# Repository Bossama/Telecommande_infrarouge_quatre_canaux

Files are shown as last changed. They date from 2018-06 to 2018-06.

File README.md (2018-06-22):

# Telecommande_infrarouge_quatre_canaux

Notre Mini Projet intituler télécommande a 4 cannas composer de deux cartes électroniques :

Le 1er est un émetteur possède 4 bouton dont chaque à leur propre période 

Le 2 -ème est un récepteur qui va traiter le signal délivrer par l’émetteur et puis (après une phase de sélection) ce signal va 
assurer soit la mise en marche ou l’arrêt de l’une des 4 canaux dont deux voix en 12V DC et deux autres en 220V AC. 

Programme utiliser : Eagle 7.7 win64
                     https://www.autodesk.com/products/eagle/overview

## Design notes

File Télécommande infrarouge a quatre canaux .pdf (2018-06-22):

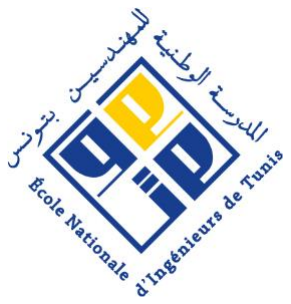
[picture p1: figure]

République Tunisienne
Ministère de l’Enseignement Supérieur et de la Recherche Scientifique Université de Tunis El Manar
Ecole Nationale d’Ingénieurs de Tunis
Département Génie Electrique

# Mini Projet d’Électronique I

# Télécommande infrarouge a quatre canaux

## Réalisé par :

## Mohamed Elhedi BOUSSAMA

## Classe : 1AGE2

## Encadré par :

## Mr AYADI Mounir & Mr HAGGEGE Joseph

Année universitaire 2016/2017

# Mini Projet Electronique 2017

iv

# Remercîments

A la fin de ce mini projet, je tiens cette occasion pour remercier vivement :

_Monsieur AYADI Mounir et monsieur HAGGEGE Joseph pour leurs explications théoriques durant les sept semaines.

_ Monsieur SAKRANI Samir pour ses conseils pratiques durant tous les tests ainsi ses explications, ses remarques pratiques qui nous aides à mieux comprendre les différentes parties de ce projet.

_ Monsieur YAHYA Jawadi qui nous assure les conditions parfaites et le matériel nécessaire au sien de laboratoire électrique …. Même l’appareille photo.

_ Monsieur HABIBE le fameux ‘ONCLE HABIBE’ qui nous aides dès le premier jour de travail : du routage jusqu’à les dernières retouches et la finalisation de ce projet…

_Finalement je vous remercie Monsieur le lecteur et je vous invite maintenant à découvrir les différentes parties de ce projet.

v

## Table des matières

vi

vii

## Table des figures

viii

ix

## Liste des tableaux

x

# Introduction générale

Une télécommande a 4 canaux ça peut être un peut bizarre en 2017 de parler de tel projet vis à vie le développement au domaine électronique microélectronique et même en parle de la nano électronique. Mais ce n’a pas l’objectif de noter projet ….

En effet ce mini projet a pour objectif : le développement des connaissances théoriques établies dans les cours d’électroniques analogiques et numériques et d’essai de l’appliquer au plan réel.

Notre Mini Projet intituler télécommande a 4 cannas composer de deux cartes électroniques :

Le 1er est un émetteur possède 4 bouton dont chaque à leur propre période

Le 2 -ème est un récepteur qui va traiter le signal délivrer par l’émetteur et puis (après une phase de sélection) ce signal va assurer soit la mise en marche ou l’arrêt de l’une des 4 canaux dont deux voix en 12V DC et deux autres en 220V AC.

NB : dans toute la suite en va introduire les différentes parties de ce projet et dans chaque partie on va présenter quelque notion théorique et leur réalisation en pratique ….

NOW LET’S DO IT …

# Chapitre 1 * ALIMENTATION *

## 1.1. Introduction :

Evidement comme tous les cartes électroniques… on a besoin d’une source d’alimentation et dans ce premier chapitre on va présenter les différents types d’alimentation utiliser

### 1.2 Circuit d’alimentation +12V :

Cette partie a pour rôle d’alimenter les différents circuits intégrer utiliser. On obtient le

+12V après les quatre étages suivants :

### 1.2.1 Transformation 220V➔2*12V :

La transformation de la tension secteur (220V) à une tension 2*12V est assurée par un transformateur abaisseur TR1 à point milieu. Donc la valeur maximale délivrer par le secondaire est :

U | U 2max = | × | = | × | = eff | 2 12 | 2 16.97 V

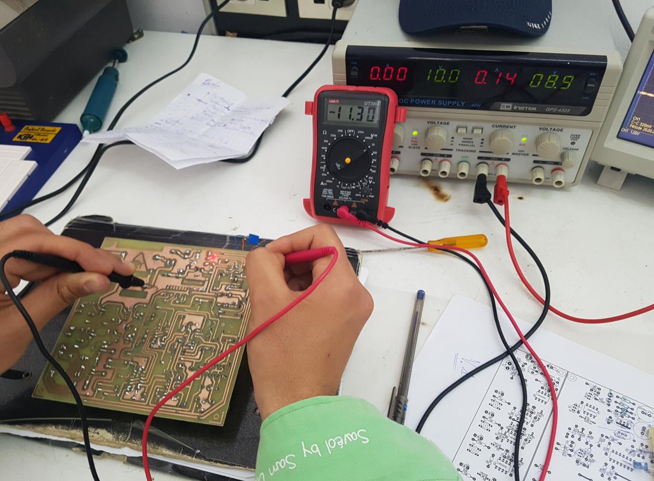
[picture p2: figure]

Figure 1 : mesure -12V

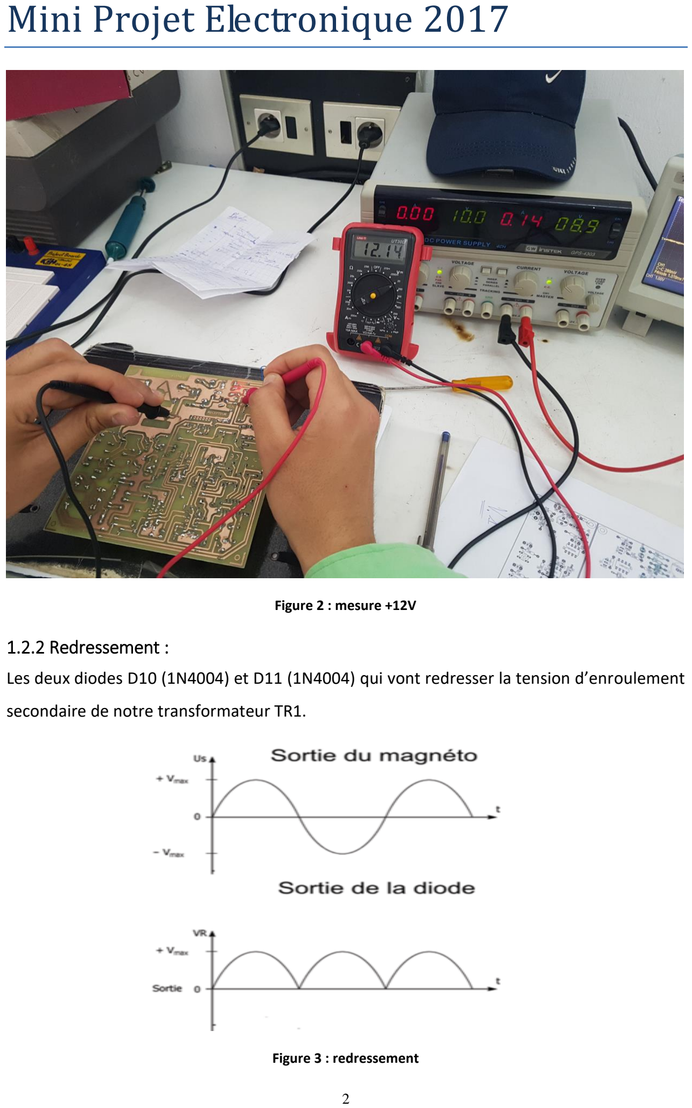
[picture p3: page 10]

Figure 2 : mesure +12V

### 1.2.2 Redressement :

Les deux diodes D10 (1N4004) et D11 (1N4004) qui vont redresser la tension d’enroulement

secondaire de notre transformateur TR1.

Figure 3 : redressement

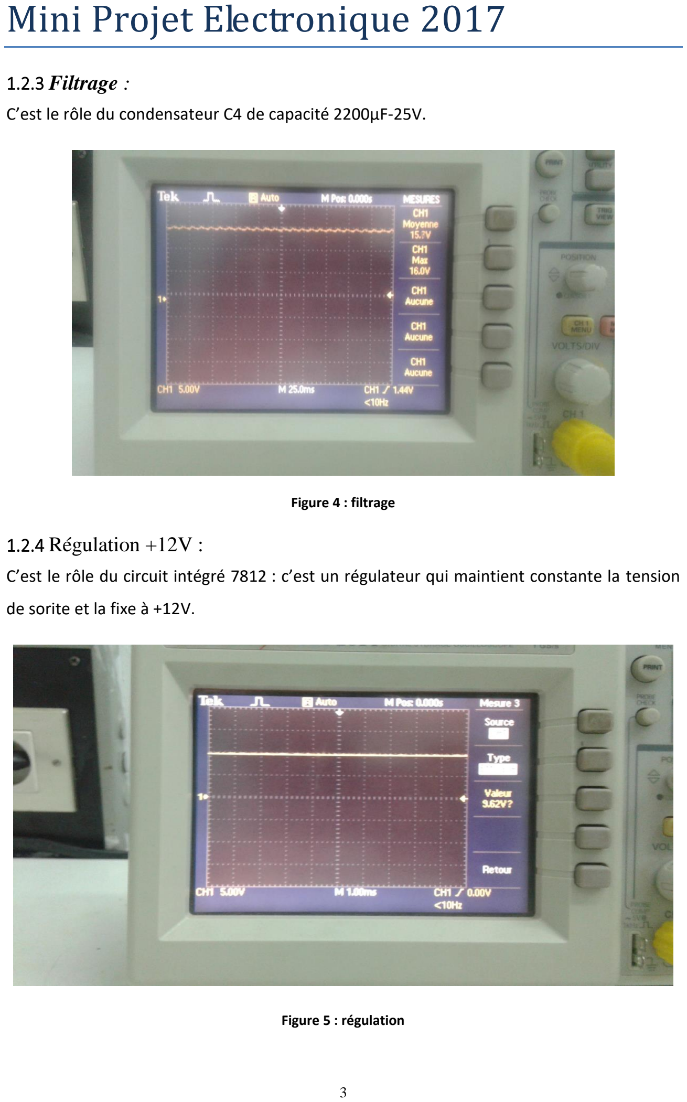
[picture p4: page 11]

### 1.2.3 Filtrage :

C’est le rôle du condensateur C4 de capacité 2200µF-25V.

Figure 4 : filtrage

### 1.2.4 Régulation +12V :

C’est le rôle du circuit intégré 7812 : c’est un régulateur qui maintient constante la tension

de sorite et la fixe à +12V.

Figure 5 : régulation

1.2.5 Témoignage :

La diode LED2 et la LED 3 sert à vérifier que la carte est bien sous tension.

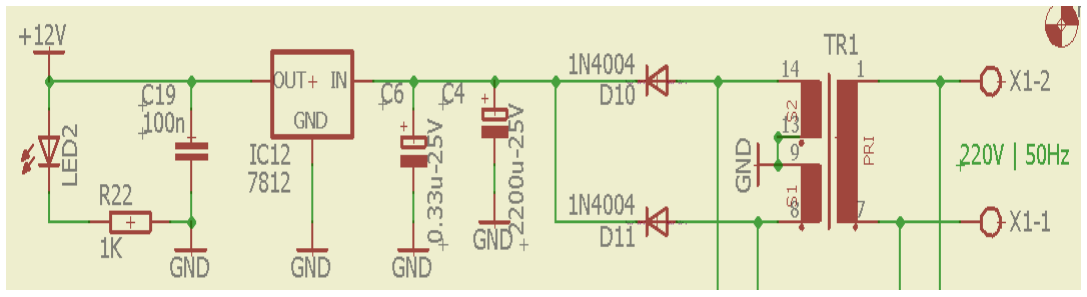
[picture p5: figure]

Figure 6 : alimentation +12V

### 1.3 Circuit d’alimentation -12V / +5V :

Comme les deux tensions -12V et +5V sont utiliser seulement pour alimenter respectivement l’intégrateur et le capteur infrarouge (faible courant) on a choisi une autre manière de régulation qui est moins cher de terme d’argent et d’espace : c’est la diode zener.

Stabilisation :

C’est le rôle de la Diode ZENER D14 ET D15

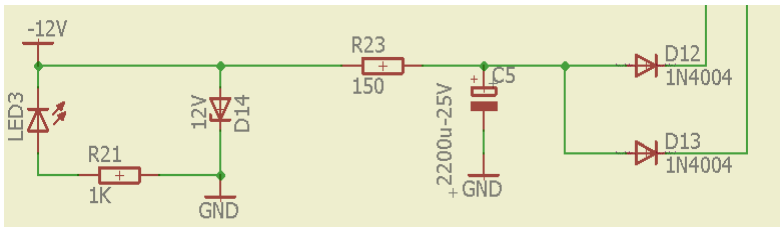
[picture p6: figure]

Figure 7 : ZENER 12V

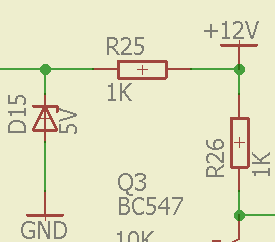
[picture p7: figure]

Figure 8 : ZENER 5V

### 1.4 Alimentation émetteur :

### Et pour le circuit de télécommande on a choisi une pile 9V comme une source

de tension continu.

# Chapitre 2 * EMETTEUR *

### 2.1 Introduction :

Dans ce chapitre on va attaquer la première partie de notre projet l’émetteur …. Qui est composée principalement du fameux circuit intégrer le NE555N

### 2.2 principe de fonctionnement :

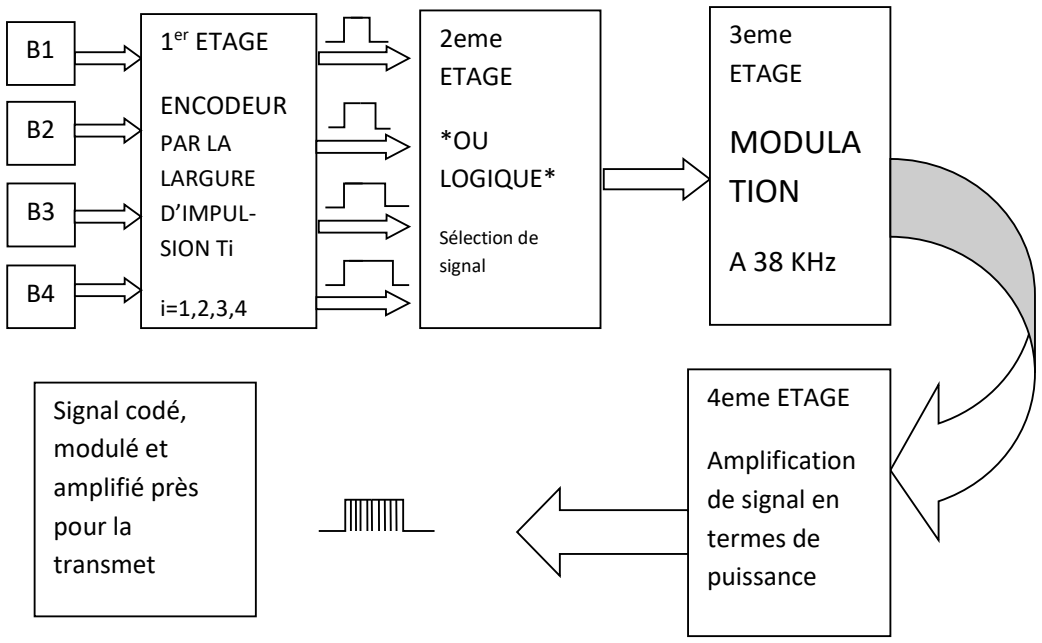
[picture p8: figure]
er ETAGE; ENCODEUR; PAR LA LARGURE D’IMPUL- SION Ti; 2eme ETAGE; *OU LOGIQUE*; Sélection de signal; 3eme ETAGE; MODULA TION; A 38 KHz; 4eme ETAGE; Amplification de signal en termes de puissance; Signal codé, modulé et amplifié près pour la transmet

### 2.3 ENCODEUR PAR LA LARGURE D’IMPULSION Ti :

Dans cette partie on utilise le NE555N on mode MONOSTABLE … on obtient des différents largueurs d’impulsion en changeant la valeur de la résistance R3.

Figure 9 : principe de fonctionnement émetteur

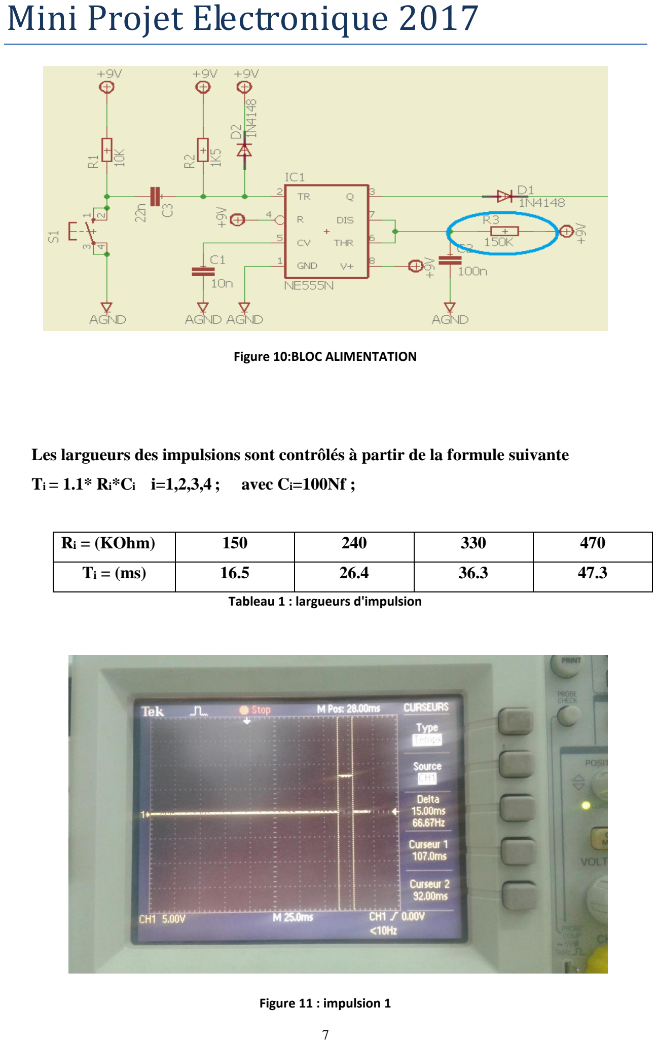
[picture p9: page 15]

Figure 10:BLOC ALIMENTATION

Les largueurs des impulsions sont contrôlés à partir de la formule suivante

Ti = 1.1* Ri*Ci | i=1,2,3,4 ; | avec Ci=100Nf ;
Ri = (KOhm) | 150 | 240 | 330 | 470
Ti = (ms) | 16.5 | 26.4 | 36.3 | 47.3

Tableau 1 : largueurs d'impulsion

Figure 11 : impulsion 1

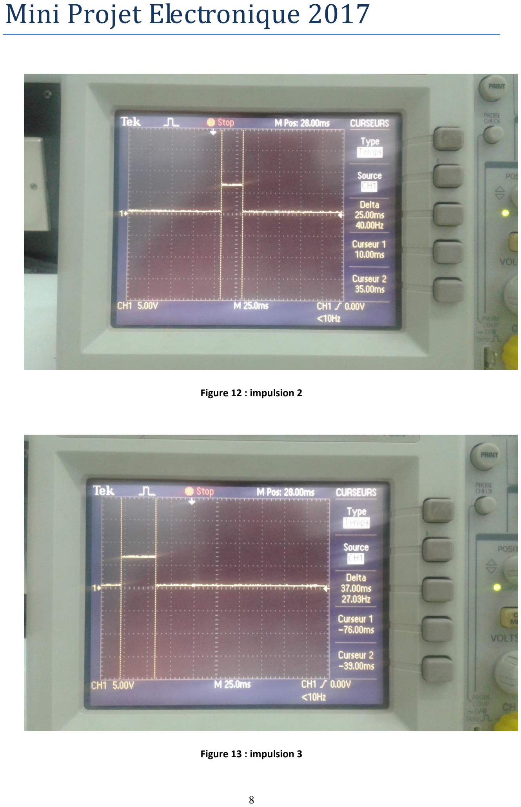
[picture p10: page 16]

Figure 12 : impulsion 2

Figure 13 : impulsion 3

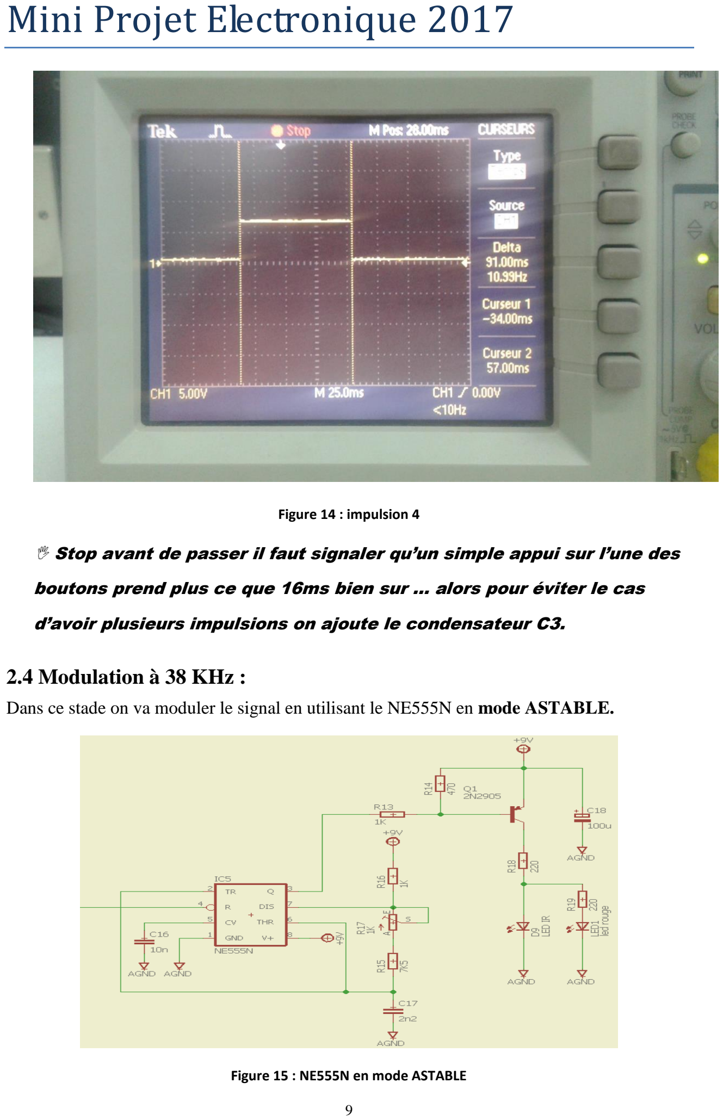
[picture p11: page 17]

Figure 14 : impulsion 4

- Stop avant de passer il faut signaler qu’un simple appui sur l’une des

boutons prend plus ce que 16ms bien sur … alors pour éviter le cas

d’avoir plusieurs impulsions on ajoute le condensateur C3.

### 2.4 Modulation à 38 KHz :

Dans ce stade on va moduler le signal en utilisant le NE555N en mode ASTABLE.

Figure 15 : NE555N en mode ASTABLE

La fréquence a la sortie est donner par la formule suivante :

F = 1/T = 1.44/(R16 + R17+ R15)* C1 comme R17 est varié entre 0 et 1K alors on obtient

Une plage de fréquence entre Fmin =36.5KHz et Fmax = 40KHz

On fixe le signal moduler a 38KHz (il faut d’abord désactiver l’entrer RESET en le

connecte au VCC).

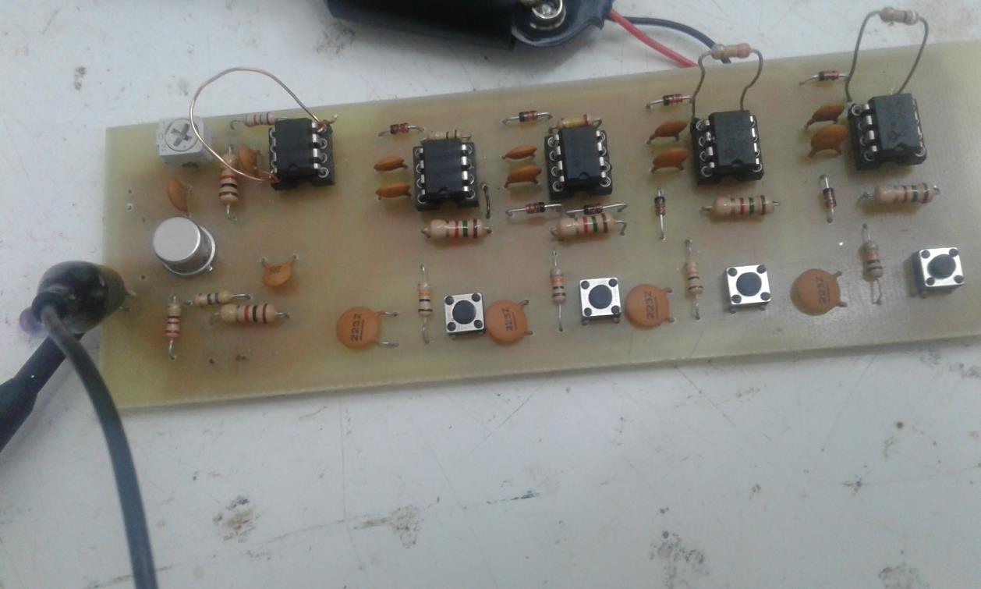
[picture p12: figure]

Figure 16 : réglage 38KHz

### 2.5 Amplification de signal en termes de puissance :

Assurer par le transistor Q1.

### 2.6 Conclusion :

Le principe de fonctionnement de cette émettrice est validé par la réalisation pratique …

Mais il faut signaler que le télécommande reste toujours active ce quoi génère une énorme consommation …. Alors il faut essaiera de concevoir un circuit de veille pour résoudre ce problème fatal.

# Chapitre 3 * RECEPTEUR *

### 3.1 Introduction

Dans ce chapitre on va attaquer le cœur de notre projet L’EMETTEUR qui se base sur les

principes suivants

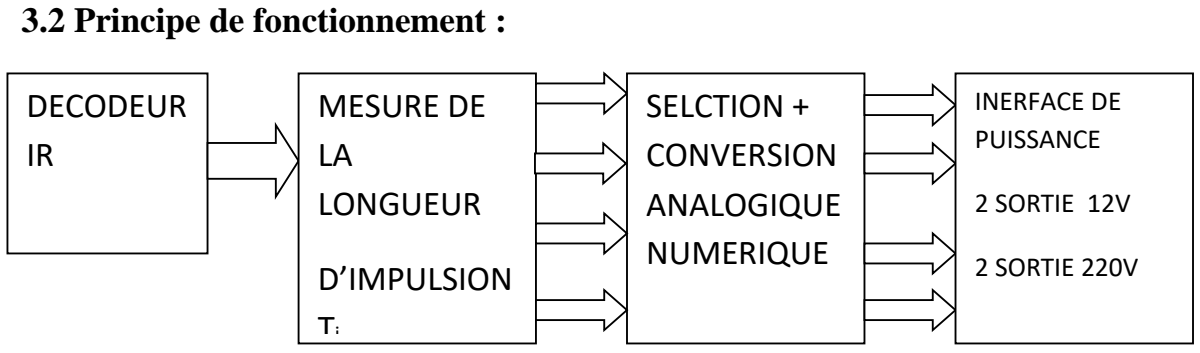
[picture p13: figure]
3.2 Principe de fonctionnement :; DECODEUR IR; MESURE DE LA LONGUEUR; D’IMPULSION Ti; SELCTION + CONVERSION ANALOGIQUE NUMERIQUE; INERFACE DE PUISSANCE; 2 SORTIE 12V; 2 SORTIE 220V

### 3.3 Décodeur IR :

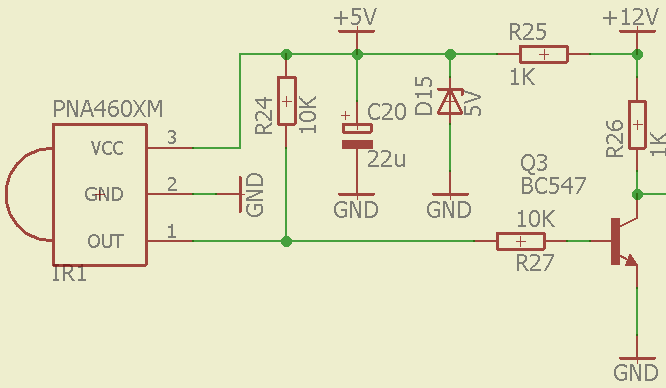
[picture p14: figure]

Figure 17 : DECODEUR IR

Figure 6 – SORTIE DECODEUR IR

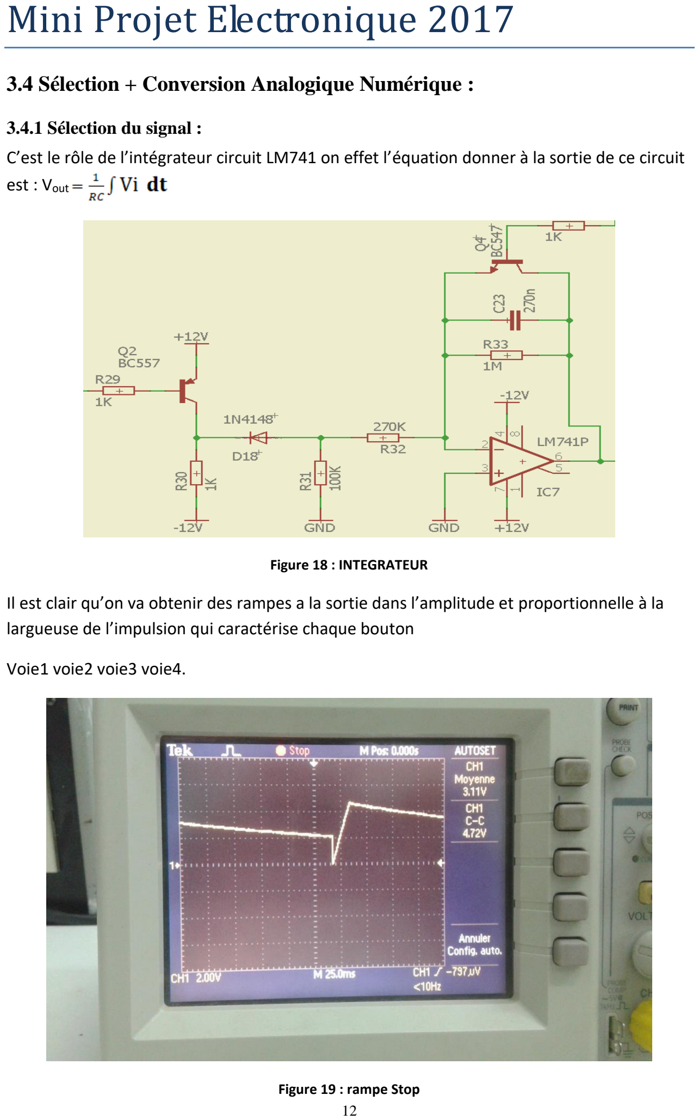
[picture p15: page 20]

### 3.4 Sélection + Conversion Analogique Numérique :

### 3.4.1 Sélection du signal :

C’est le rôle de l’intégrateur circuit LM741 on effet l’équation donner à la sortie de ce circuit est : Vout

Figure 18 : INTEGRATEUR

Il est clair qu’on va obtenir des rampes a la sortie dans l’amplitude et proportionnelle à la largueuse de l’impulsion qui caractérise chaque bouton

Voie1 voie2 voie3 voie4.

Figure 19 : rampe Stop

### NB : on ne peut jamais observer les rampes en utilisant le RUN/STOP il se

peut que la rampe n’atteint pas leur maximum avant l’appuis sur STOP.

### Pour résoudre le problème on a utilisé le ‘’ONE SCREEN SHOT MODE ’’

THNX M. HAGGEGE ☺.

ONE SCREEN SHOT MODE :

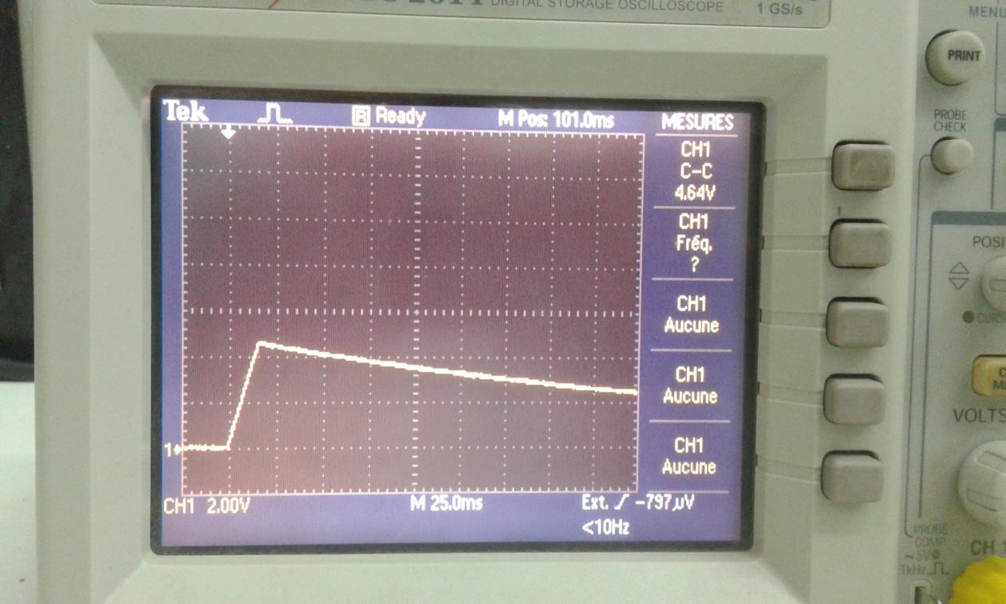
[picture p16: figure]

Figure 20 : rampe T1=16ms

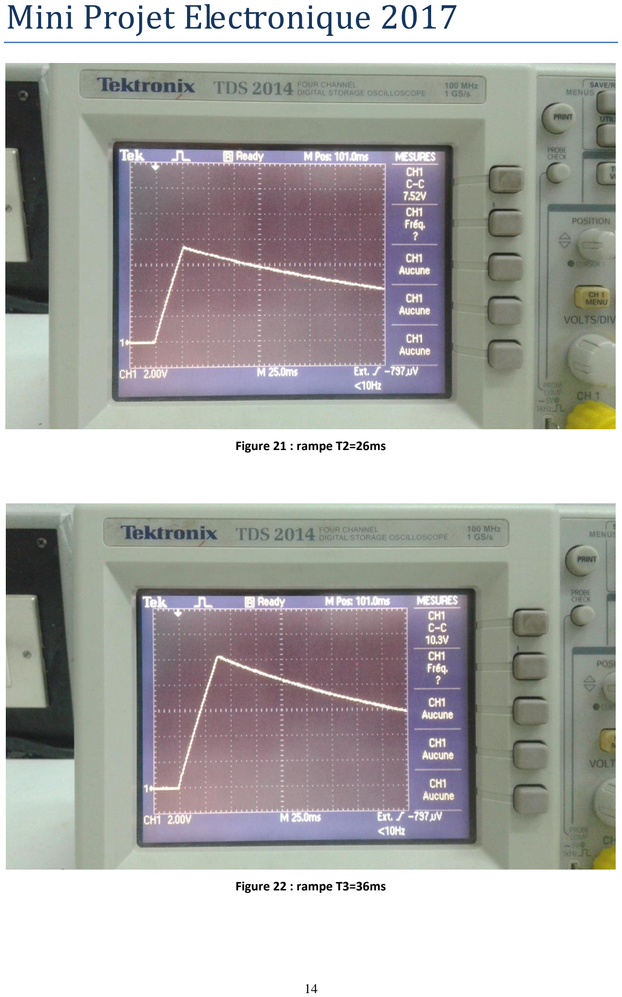
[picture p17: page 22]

Figure 21 : rampe T2=26ms

Figure 22 : rampe T3=36ms

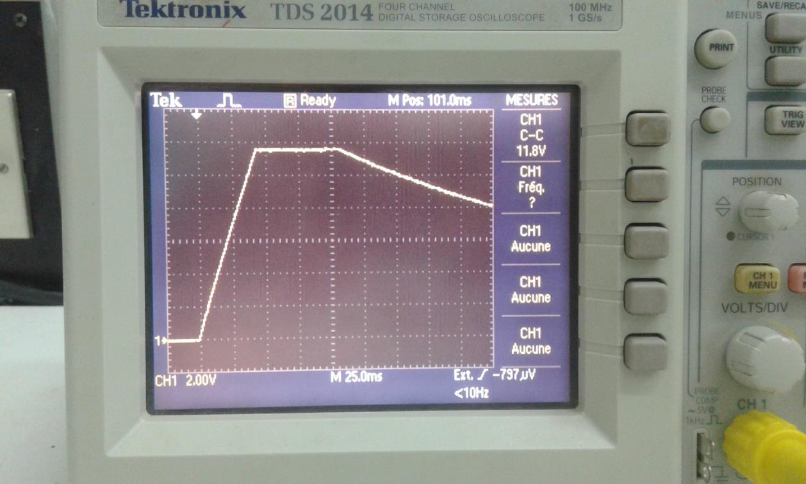
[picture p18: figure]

Figure 23 : rampe T4=90ms

### Maintenant on va injecter cette rampe dans une suite des comparateurs pour

sélectionner la sortie désirée.

### Comme il apparut des problèmes inattendus dans le pratique (interne échange entre les boutons et les sorties). L’auteur de cette rapport essai de faire élargir les intervalles de sélection comme indique le tableau suivant :

R41 =R40 =R39 =R38 = R | R=10K | R=13K | R=15K | R=22K
V1 -= | 1.93 | 2.1 | 2.19 | 2.4
V2 -= | 3.87 | 4.2 | 4.4 | 4.8
V3 -= | 5.8 | 6.3 | 6.6 | 7.2
V4 -= | 7.74 | 8.4 | 8.8 | 9.6

Tableau 2 : diffèrent valeur de Comparaison

### Chaque comparateur sa fonctionne si Vi

+ ≥ Vi

### - alors on obtient le tableau suivant :

+ Vi | V1 -=1.9V | V1 -=3.87V | V1 -=5.8V | V1 -=7.74V
≤V1=2,4V | 0 | 0 | 0 | 0
[2,4 ...4,8[ | 1 | 0 | 0 | 0
[4,8 ...7,2[ | 1 | 1 | 0 | 0
[7,2 ...9,6[ | 1 | 1 | 1 | 0
≥9,6V | 1 | 1 | 1 | 1

Tableau 3 : Sortie Comparateur

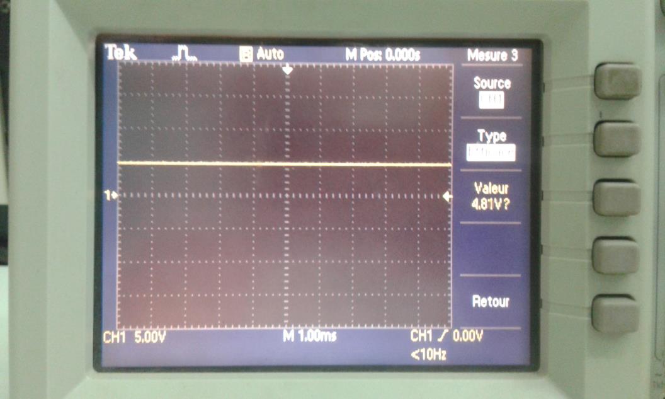
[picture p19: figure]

Figure 24 : tension 1 à comparer

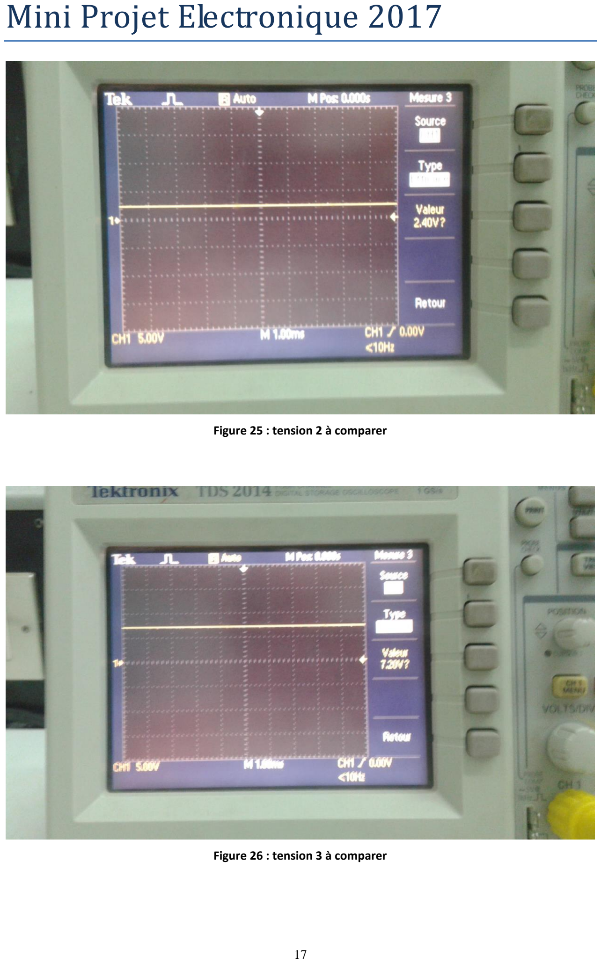
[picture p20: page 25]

Figure 25 : tension 2 à comparer

Figure 26 : tension 3 à comparer

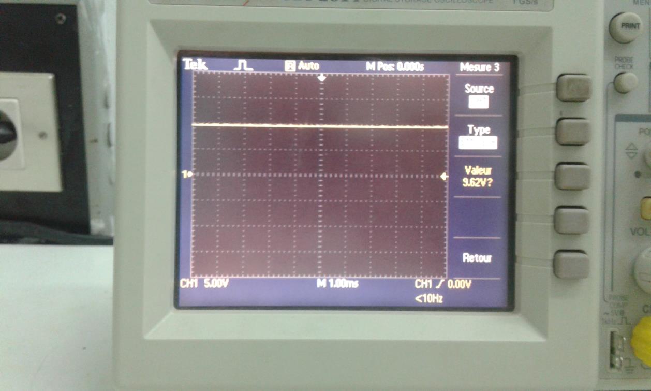
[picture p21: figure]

Figure 27 : tension 4 à comparer

### 3.4.2 CONVERSION ANALOGIQUE NUMERIQUE :

En remarque à la fin de la partie précédente que chaque voie va activer les voies précédentes pour cela on a choisi de mémoriser les voies sélectionner par la bascule ^D^ CI 4013

Puis chaque voie va annuler les voies précédentes à travers les DIODES D25 D24 D23

Enfin le bit désirer sera transmettre à l’interface de puissance à travers les bascules JK CI 4027

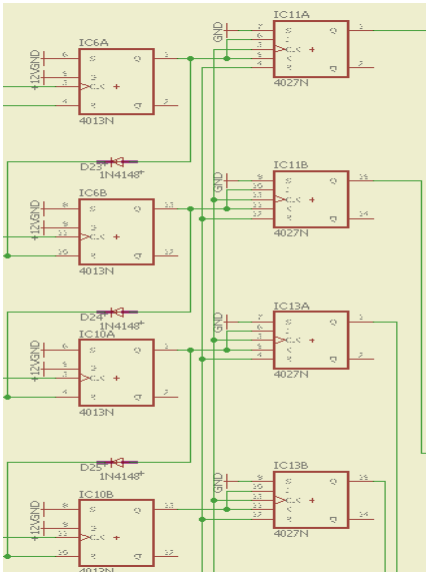
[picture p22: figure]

Figure 28 : AN

### 3.5 Interface de Puissance :

### 3.5.1 Voies +12V :

On a choisi deux relais +12v

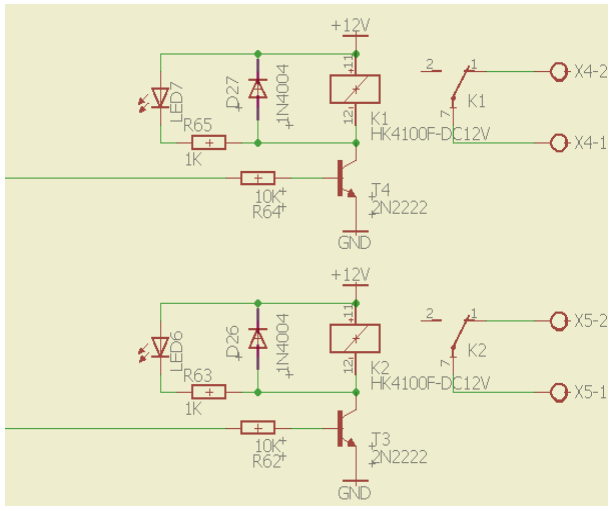
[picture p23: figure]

Figure 29 : relais

### 3.5.2 Voies +220V :

Deux opto triac MOC3041M.

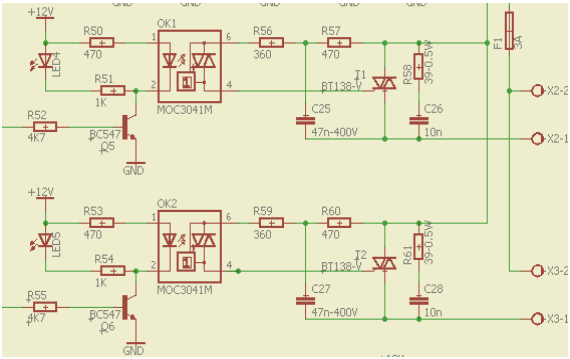
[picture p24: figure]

Figure 30 : triac

# Conclusion générale :

### Trois voies seulement qui marche … on peut expliquer ce résultat par la

précision médiocre des composants.

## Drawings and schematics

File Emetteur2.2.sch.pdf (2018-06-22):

# +12V 10K 10K 10K 10K

# R33 C22 C23 Q⁴

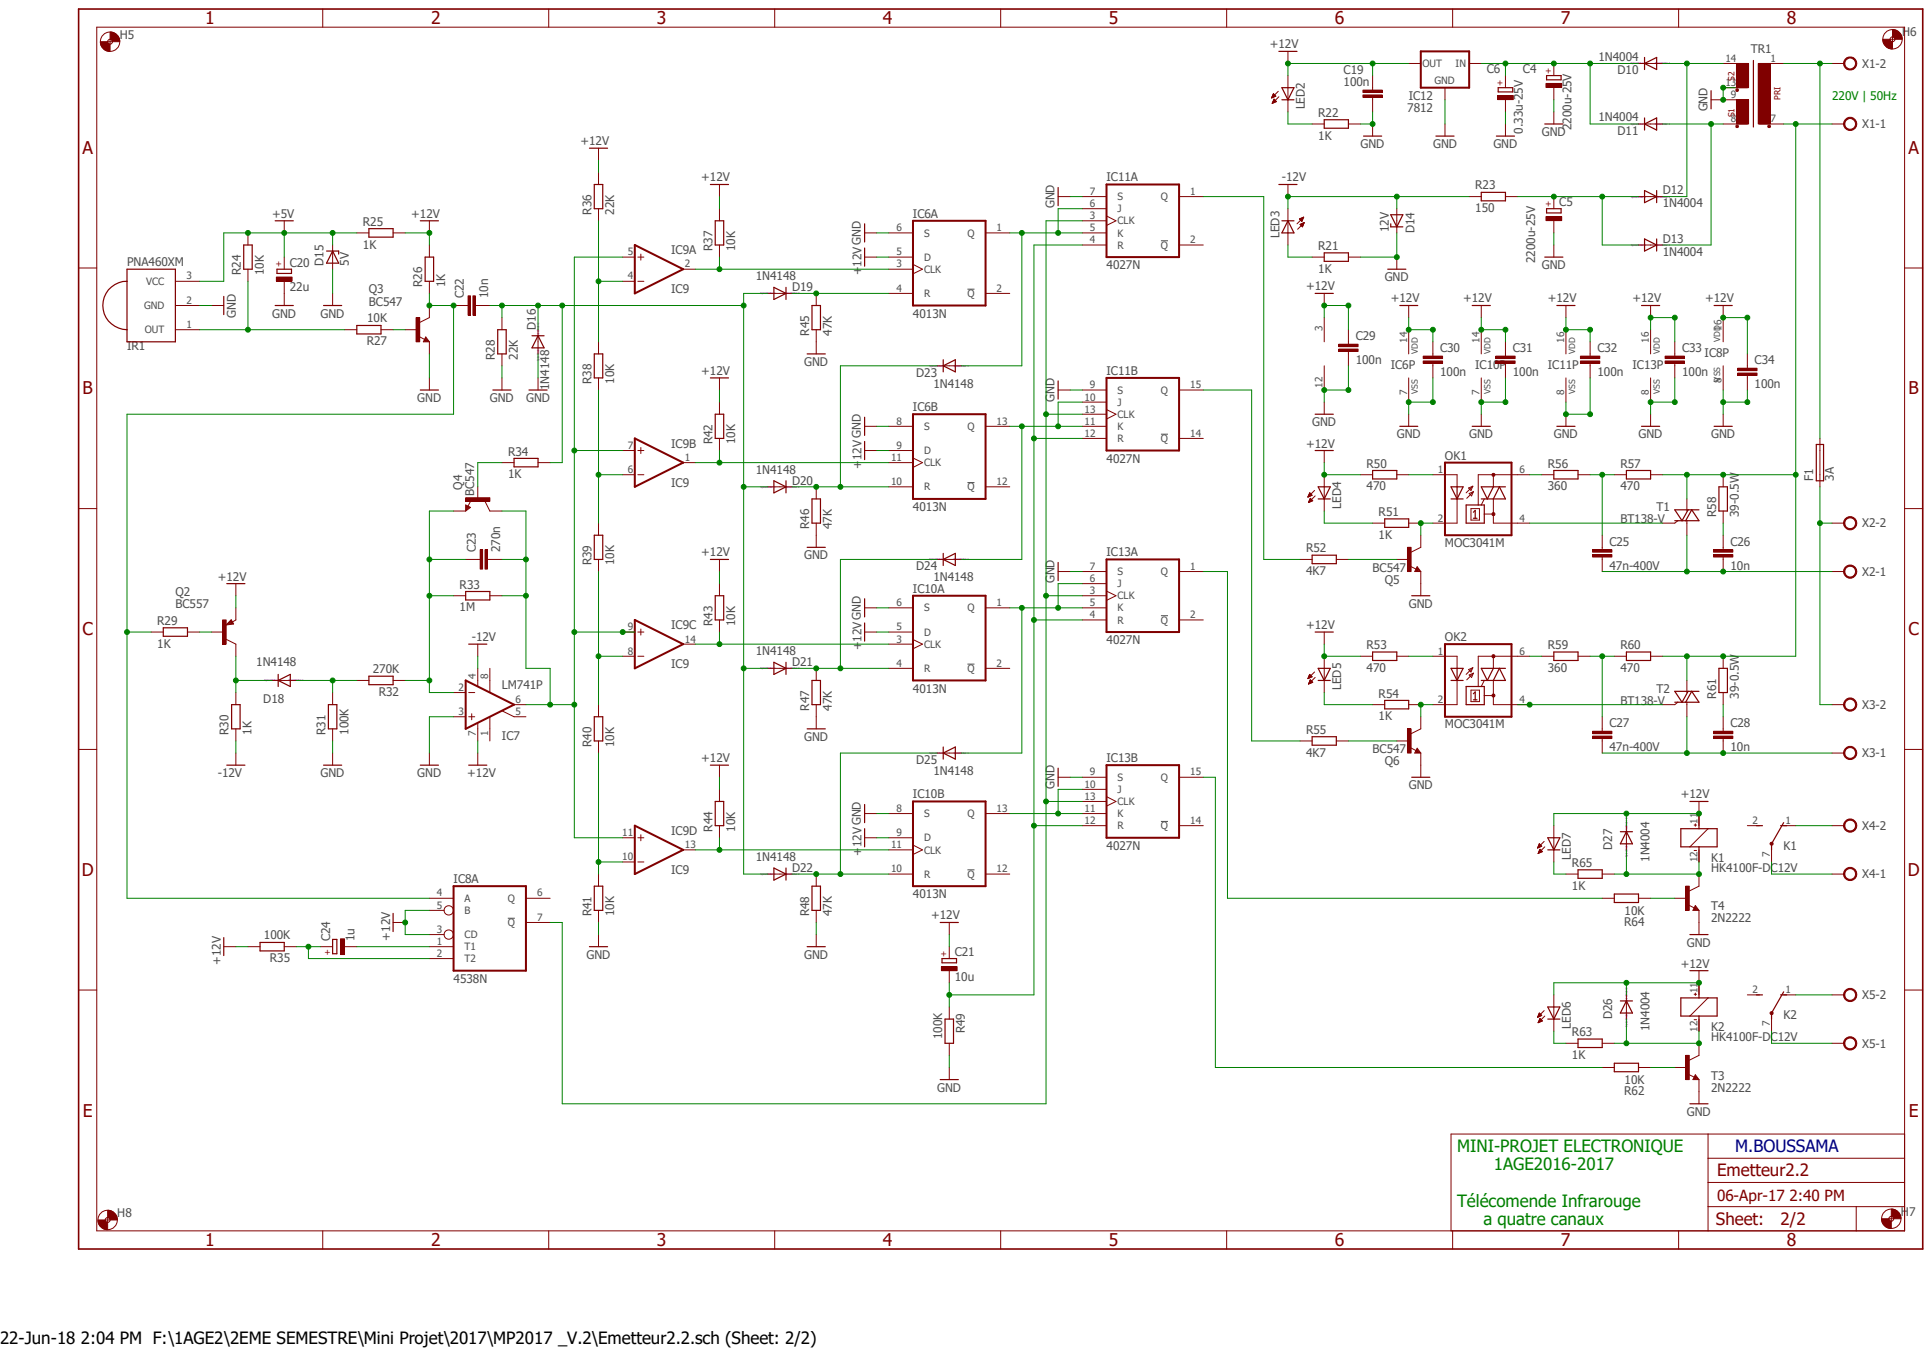
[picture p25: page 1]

GND GND

GND GND GND GND +12V +12V +12V +12V

SpiceOrder 1 SpiceOrder 2

22-Jun-18 2:04 PM F:\1AGE2\2EME SEMESTRE\Mini Projet\2017\MP2017 _V.2\Emetteur2.2.sch (Sheet: 2/2)

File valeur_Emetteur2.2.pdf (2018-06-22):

# 05/04/2017 21:36 C:\Users\Boussama\Documents\eagle\MP2017\Emetteur2.2.brd ¹K

S1 | P1

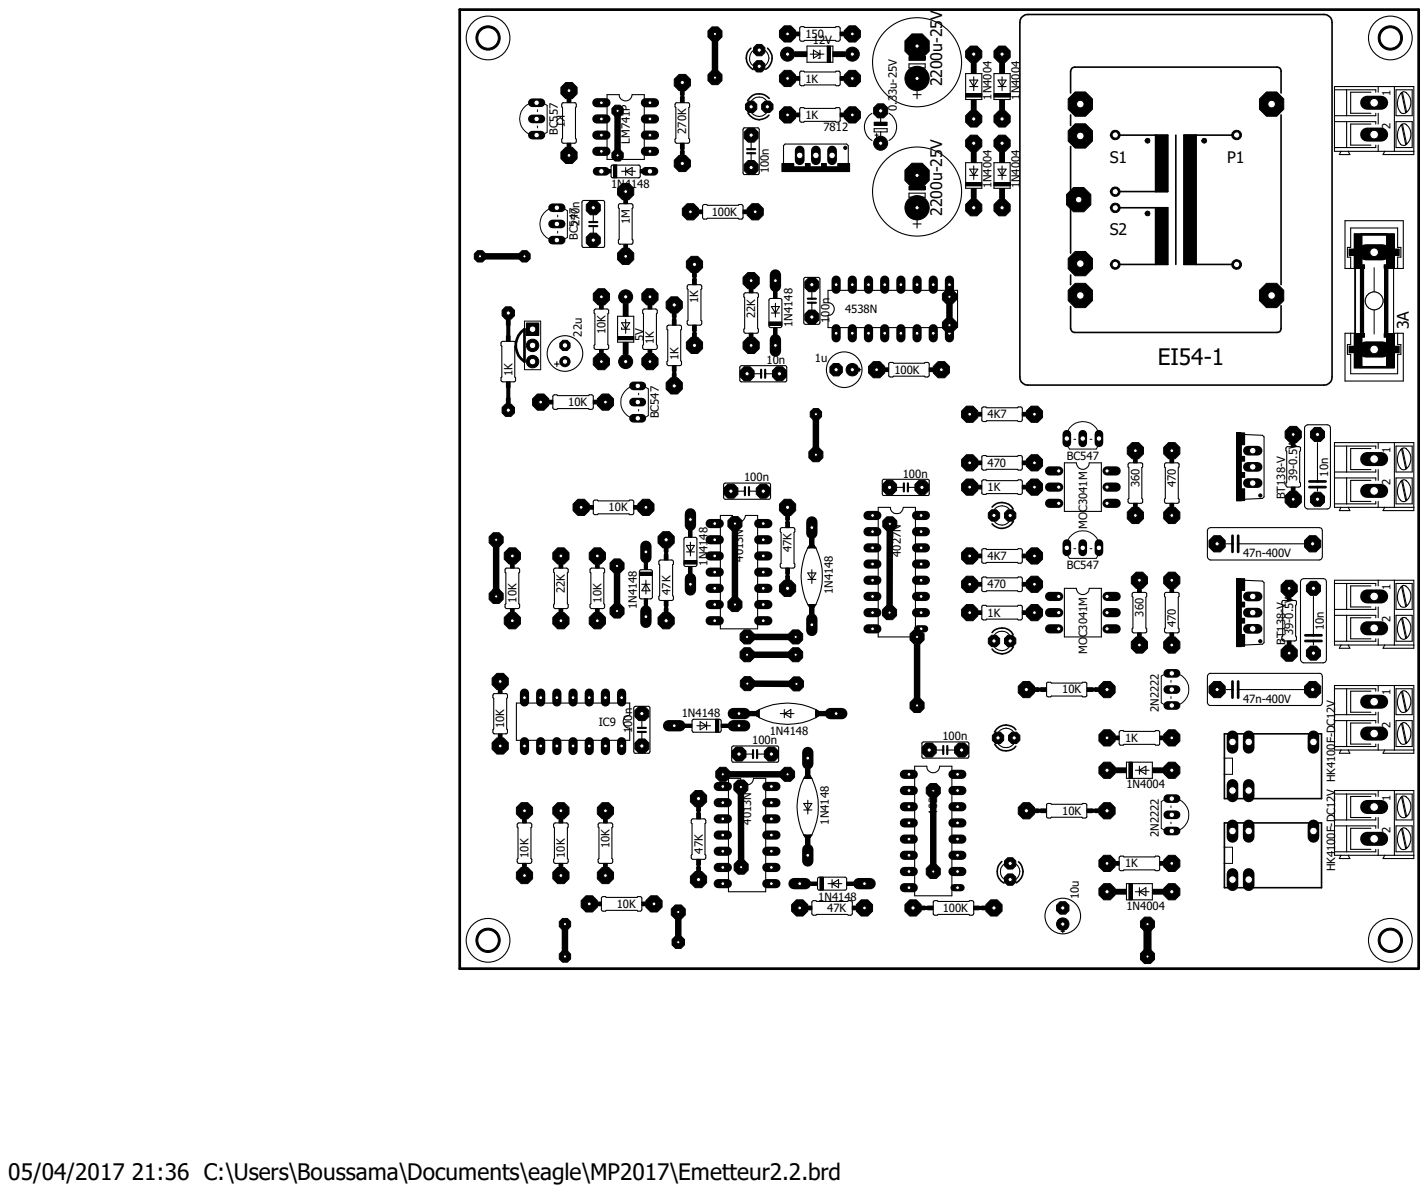
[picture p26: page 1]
1N41481N⁴¹⁴⁸; MOC3041M MOC3041M

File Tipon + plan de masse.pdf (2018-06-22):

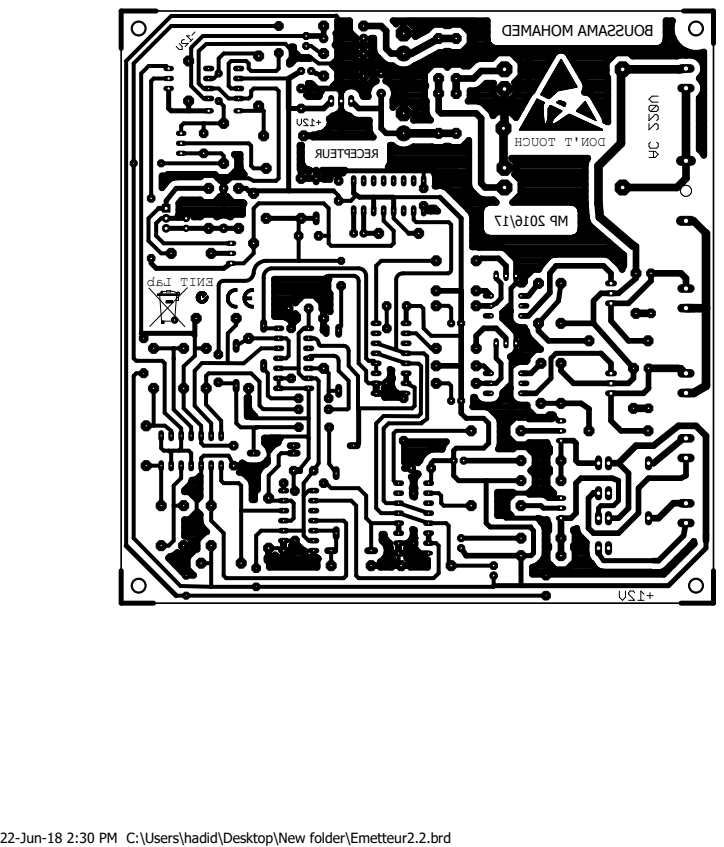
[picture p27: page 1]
DON'T TOUCH; BOUSSAMA MOHAMED; RECEPTEUR; ENIT Lab

22-Jun-18 2:30 PM C:\Users\hadid\Desktop\New folder\Emetteur2.2.brd

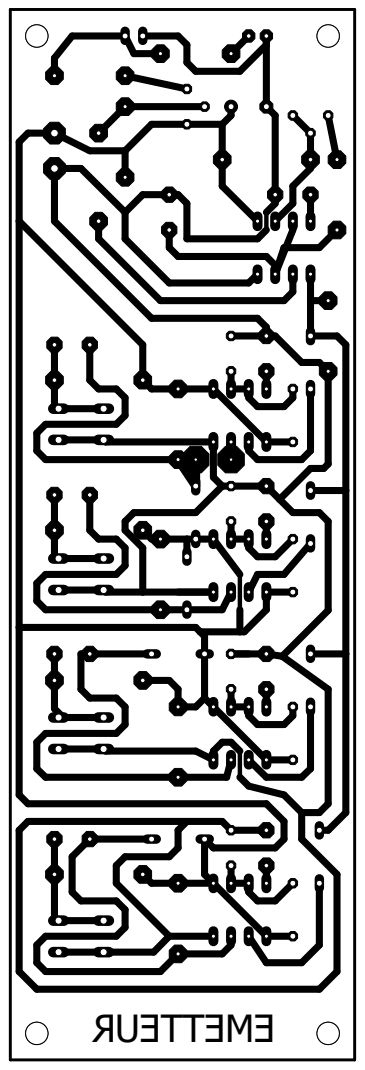
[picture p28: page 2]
EMETTEUR

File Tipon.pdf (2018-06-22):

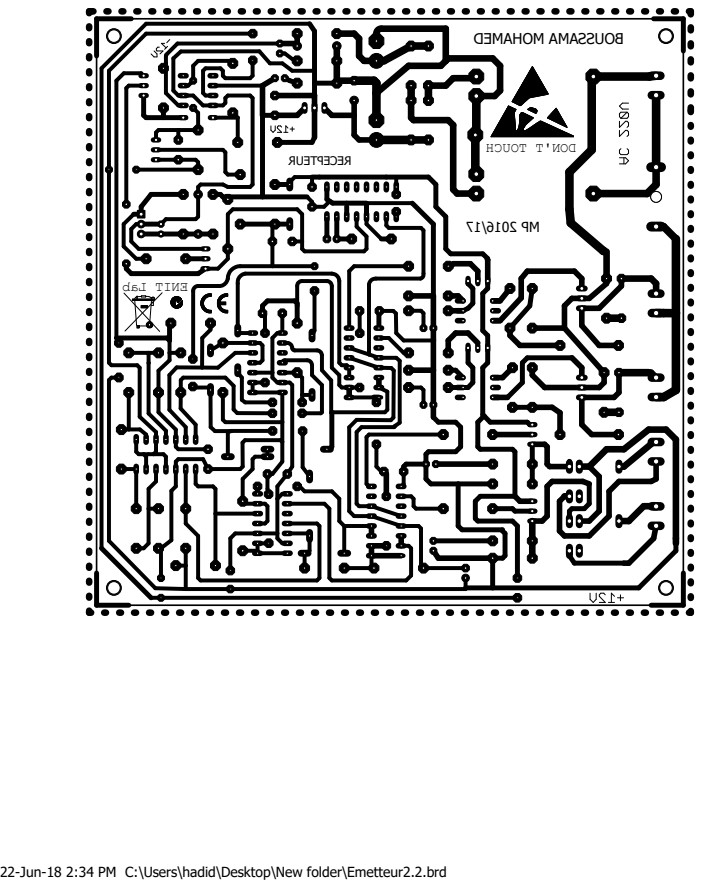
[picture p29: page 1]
DON'T TOUCH; BOUSSAMA MOHAMED; RECEPTEUR; ENIT Lab

22-Jun-18 2:34 PM C:\Users\hadid\Desktop\New folder\Emetteur2.2.brd

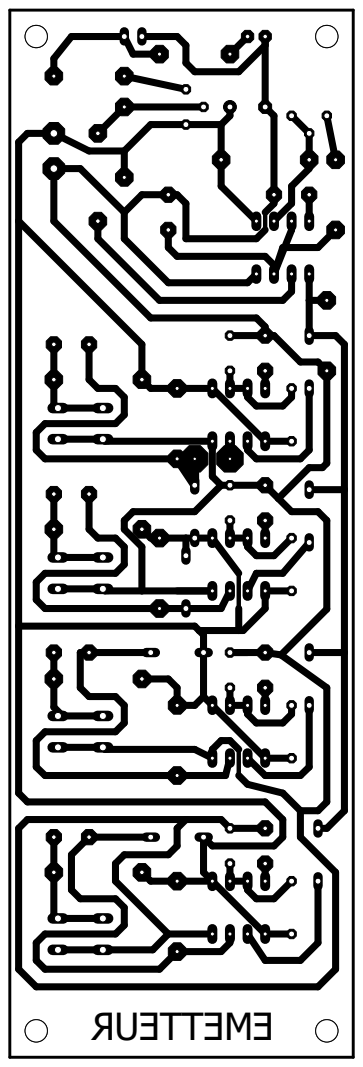
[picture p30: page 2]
EMETTEUR

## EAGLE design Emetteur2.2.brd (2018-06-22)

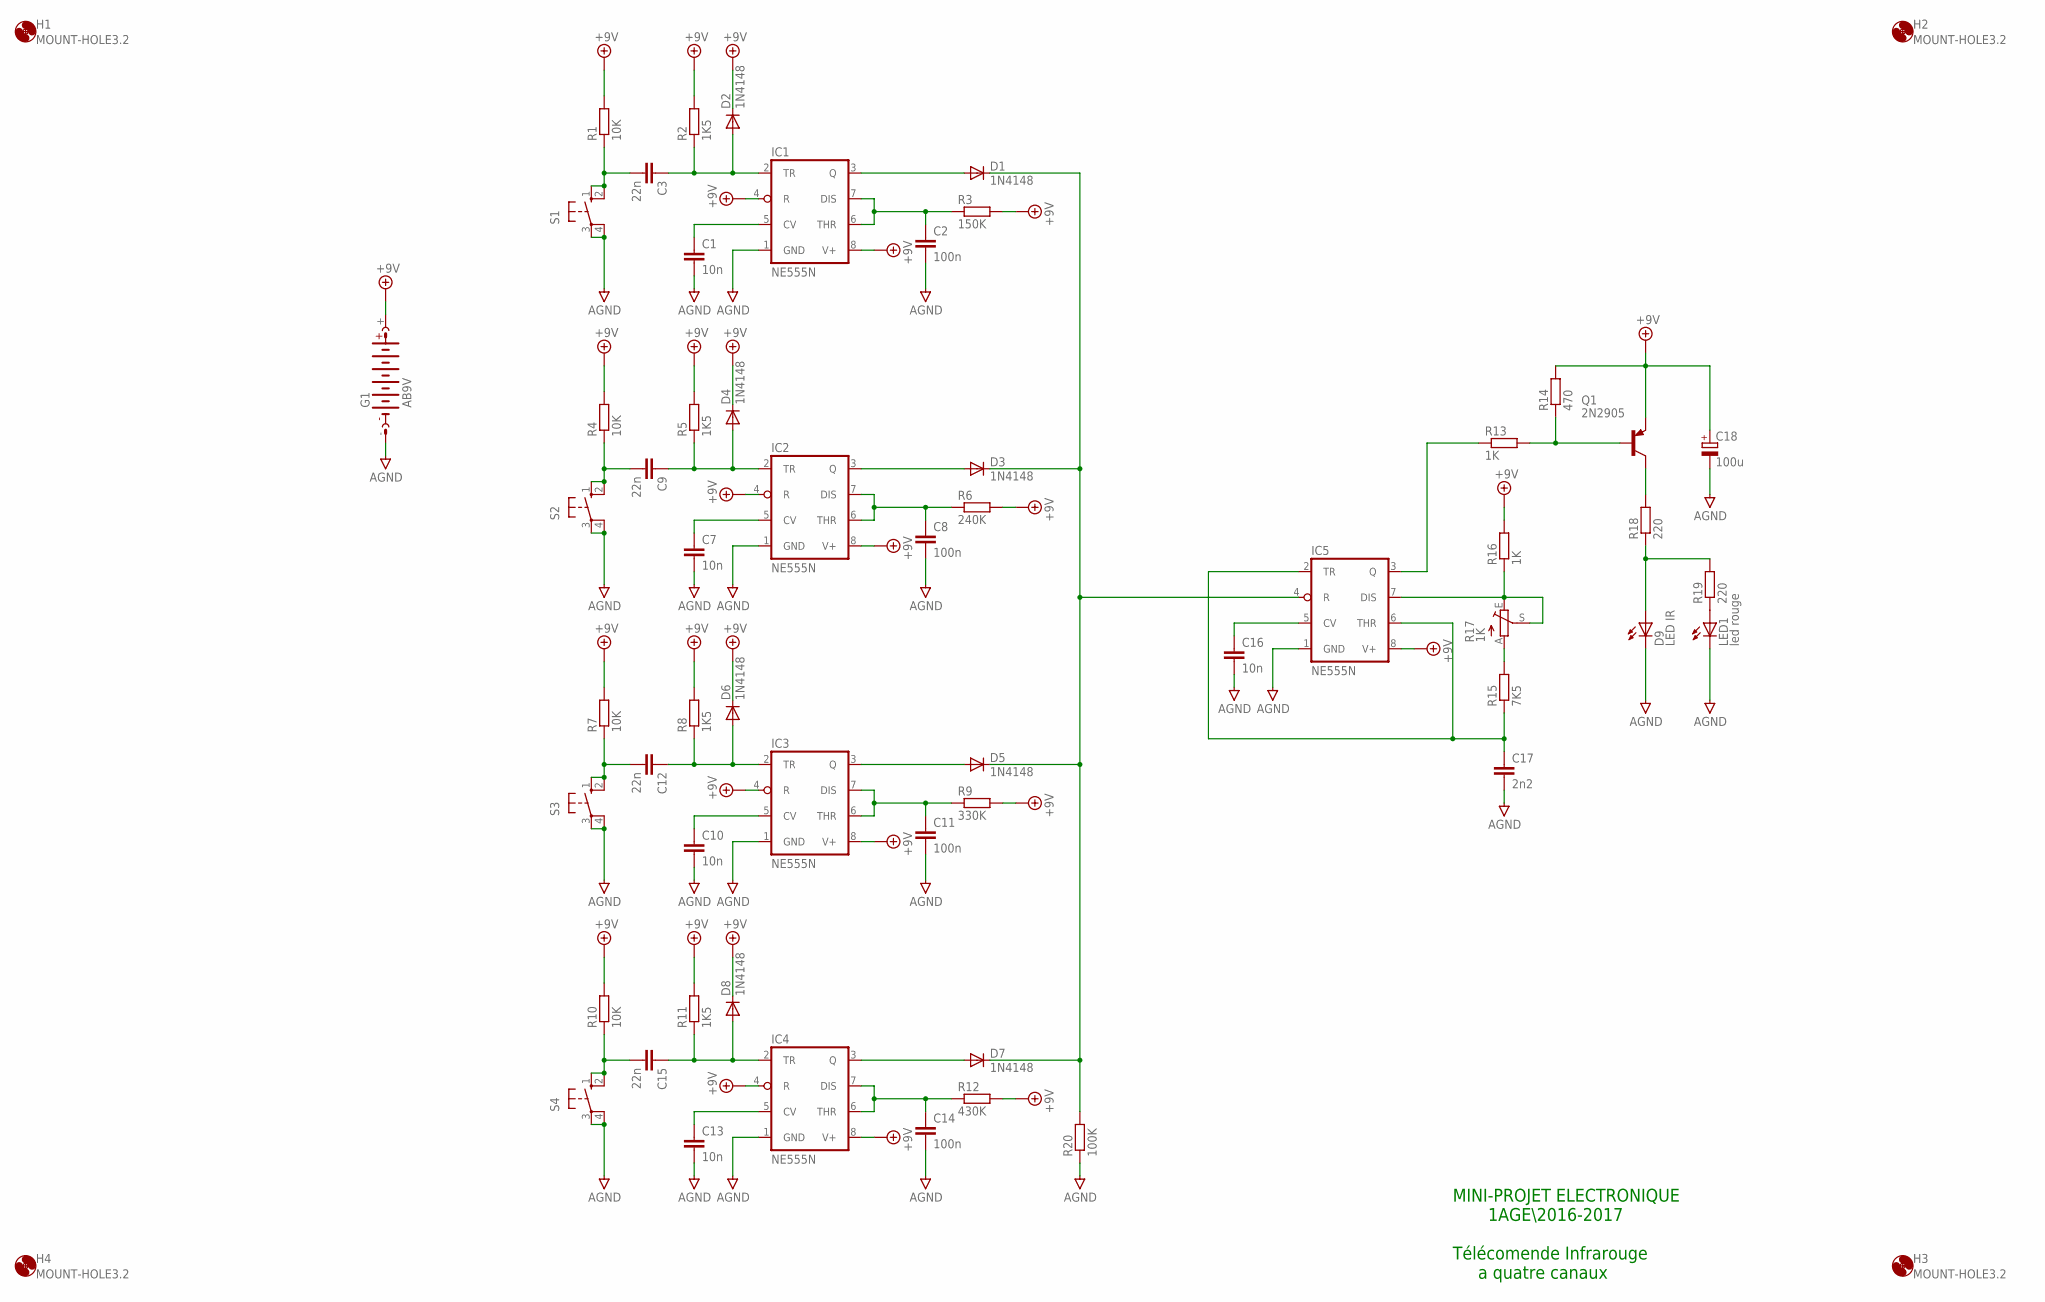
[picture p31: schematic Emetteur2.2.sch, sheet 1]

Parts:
C1, C7, C10, C13, C16: 10n; C050-025X075
C2, C8, C11, C14: 100n; C050-030X075
C3, C9, C12, C15: 22n; C050-025X075
C17: 2n2; C050-025X075
C18: 100u; E5-4
D1, D2, D3, D4, D5, D6, D7, D8: 1N4148; DO35-7
D9: LED IR; SFH482
G1: AB9V
H1, H2, H3, H4: MOUNT-HOLE3.2; 3,2
IC1, IC2, IC3, IC4, IC5: NE555N; DIL08
LED1: led rouge; LED3MM
Q1: 2N2905; TO5
R1, R4, R7, R10: 10K; 0207/12
R2, R5, R8, R11: 1K5; 0207/10
R3: 150K; 0204/7
R6: 240K; 0204/7
R9: 330K; 0204/7
R12: 430K; 0204/7
R13, R16: 1K; 0207/12
R14: 470; 0207/10
R15: 7K5; 0207/10
R17: 1K; B25P
R18, R19: 220; 0207/10
R20: 100K; 0207/10
S1: B3F-10XX
S2, S3, S4: 10-XX; B3F-10XX

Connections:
+9V: C18.+, D2.C, D4.C, D6.C, D8.C, G1.+, IC1.4 (R), IC1.8 (V+), IC2.4 (R), IC2.8 (V+), IC3.4 (R), IC3.8 (V+), IC4.4 (R), IC4.8 (V+), IC5.8 (V+), Q1.1 (E), R1.2, R2.2, R3.2, R4.2, R5.2, R6.2, R7.2, R8.2, R9.2, R10.2, R11.2, R12.2, R14.2, R16.2
AGND: C1.2, C2.2, C7.2, C8.2, C10.2, C11.2, C13.2, C14.2, C16.2, C17.2, C18.-, D9.K (C), G1.-, IC1.1 (GND), IC2.1 (GND), IC3.1 (GND), IC4.1 (GND), IC5.1 (GND), LED1.K (C), R20.1, S1.3, S1.4 (P1), S2.3, S2.4 (P1), S3.3, S3.4 (P1), S4.3, S4.4 (P1)
unnamed: C1.1, IC1.5 (CV)
unnamed: C3.1, D2.A, IC1.2 (TR), R2.1
unnamed: C2.1, IC1.6 (THR), IC1.7 (DIS), R3.1
unnamed: C3.2, R1.1, S1.1 (S), S1.2 (S1)
unnamed: D1.A, IC1.3 (Q)
unnamed: IC5.3 (Q), R13.1
unnamed: C7.1, IC2.5 (CV)
unnamed: C9.1, D4.A, IC2.2 (TR), R5.1
unnamed: C8.1, IC2.6 (THR), IC2.7 (DIS), R6.1
unnamed: C9.2, R4.1, S2.1 (S), S2.2 (S1)
unnamed: D3.A, IC2.3 (Q)
unnamed: D1.C, D3.C, D5.C, D7.C, IC5.4 (R), R20.2
unnamed: C10.1, IC3.5 (CV)
unnamed: C12.1, D6.A, IC3.2 (TR), R8.1
unnamed: C11.1, IC3.6 (THR), IC3.7 (DIS), R9.1
unnamed: C12.2, R7.1, S3.1 (S), S3.2 (S1)
unnamed: D5.A, IC3.3 (Q)
unnamed: Q1.3 (C), R18.2
unnamed: C13.1, IC4.5 (CV)
unnamed: C15.1, D8.A, IC4.2 (TR), R11.1
unnamed: C14.1, IC4.6 (THR), IC4.7 (DIS), R12.1
unnamed: C15.2, R10.1, S4.1 (S), S4.2 (S1)
unnamed: D7.A, IC4.3 (Q)
unnamed: R15.2, R17.A
unnamed: C16.1, IC5.5 (CV)
unnamed: C17.1, IC5.2 (TR), IC5.6 (THR), R15.1
unnamed: IC5.7 (DIS), R16.1, R17.E, R17.S
unnamed: Q1.2 (B), R13.2, R14.1
unnamed: D9.A, R18.1, R19.2
unnamed: LED1.A, R19.1

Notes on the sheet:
MINI-PROJET ELECTRONIQUE 1AGE\2016-2017 Télécomende Infrarouge a quatre canaux

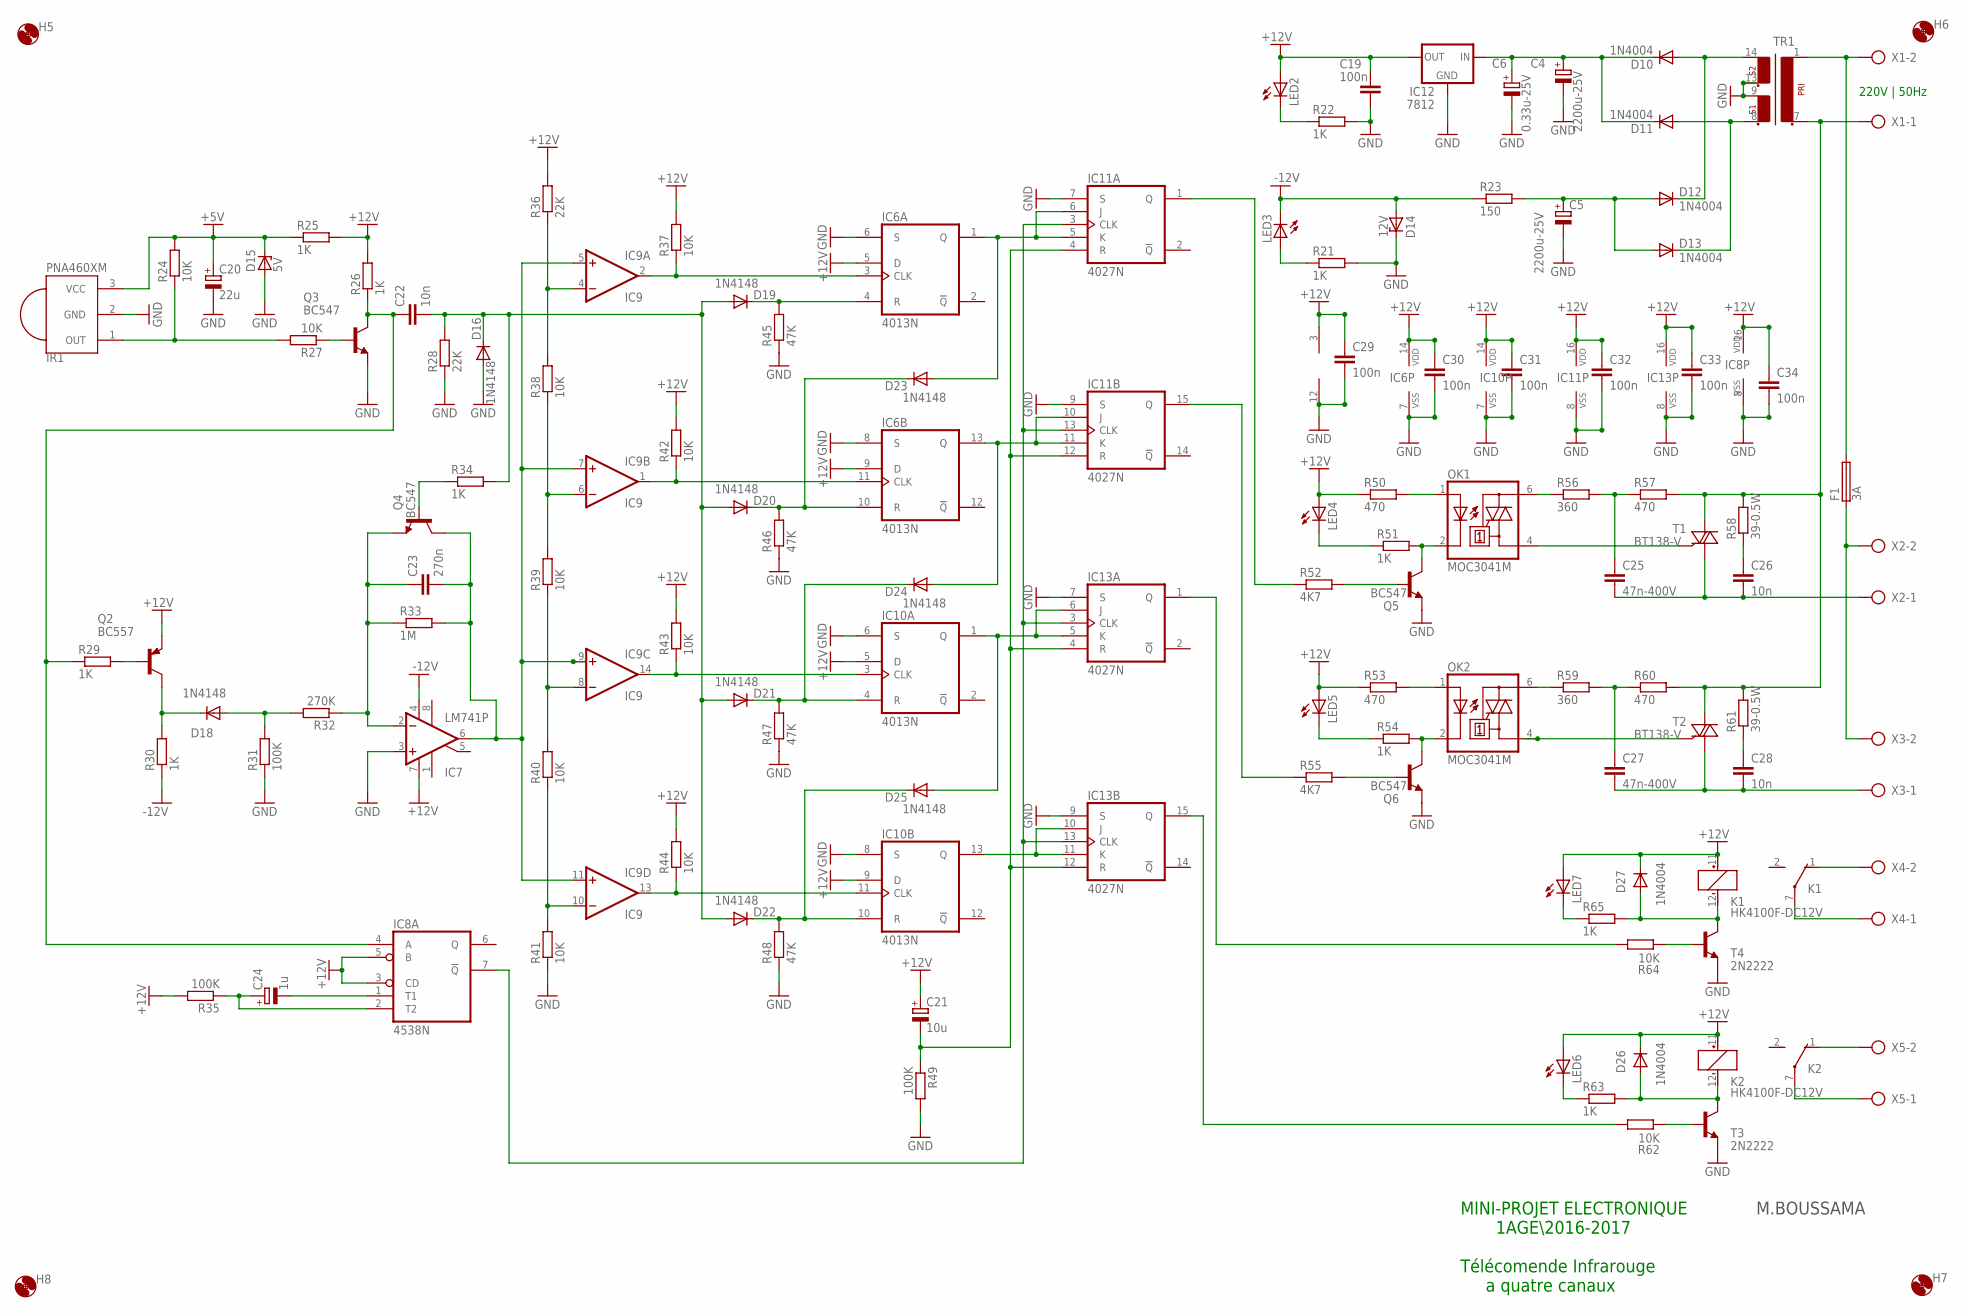
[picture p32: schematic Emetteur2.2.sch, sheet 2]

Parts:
C4, C5: 2200u-25V; E5-13
C6: 0.33u-25V; E5-5
C19, C29, C30, C31, C32, C33, C34: 100n; C050-025X075
C20: 22u; E2,5-6
C21: 10u; E2,5-6E
C22: 10n; C050-025X075
C23: 270n; C050-035X075
C24: 1u; E2,5-6E
C25, C27: 47n-400V; C150-054X183
C26, C28: 10n; C102-043X133
D10, D11, D12, D13, D26, D27: 1N4004; DO41-10
D14: 12V; DO41Z10
D15: 5V; DO41Z10
D16, D19, D21, D23, D25: 1N4148; DO35-10
D18: 1N4148; DO35-7
D20, D22, D24: 1N4148; SOD61B
F1: 3A; GSH15
H5, H6, H7, H8: MOUNT-HOLE3.2; 3,2
IC6, IC10: 4013N; DIL14
IC7: LM741P; DIL08
IC8: 4538N; DIL16
IC9: IC9; DIL14
IC11, IC13: 4027N; DIL16
IC12: 7812; 78XXS
IR1: PNA460XM
K1, K2: HK4100F-DC12V; SMR1
LED2, LED3, LED4, LED5, LED6, LED7: LED3MM
OK1, OK2: MOC3041M; DIL06
Q2: BC557; TO92-EBC
Q3, Q4, Q5, Q6: BC547; TO92-EBC
R21, R22, R25, R30, R51, R54, R63, R65: 1K; 0207/10
R23: 150; 0207/10
R24, R27, R37, R38, R39, R40, R41, R42, R43, R44: 10K; 0207/10
R26, R34: 1K; 0207/12
R28, R36: 22K; 0207/10
R29: 1K; 0207/15
R31, R35: 100K; 0207/10
R32: 270K; 0207/12
R33: 1M; 0207/10
R45, R46, R47: 47K; 0207/12
R48: 47K; 0207/10
R49: 100K; 0207/12
R50, R53, R57, R60: 470; 0207/10
R52, R55: 4K7; 0207/10
R56, R59: 360; 0207/10
R58, R61: 39-0.5W; 0207/10
R62, R64: 10K; 0207/12
T1, T2: BT138-V; TO220BV
T3, T4: 2N2222; TO92-EBC-OVAL
TR1: EI54-2
X1, X2, X3, X4, X5: AK300/2

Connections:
+5V: C20.+, D15.C, IR1.3 (VCC), R24.2, R25.1
+12V: C19.1, C21.+, C29.1, C30.1, C31.1, C32.1, C33.1, C34.1, D26.C, D27.C, IC6.5 (D), IC6.9 (D), IC6.14 (VDD), IC7.7 (V+), IC8.3 (CD), IC8.5 (B), IC8.16 (VDD), IC9.3 (V+), IC10.5 (D), IC10.9 (D), IC10.14 (VDD), IC11.16 (VDD), IC12.OUT, IC13.16 (VDD), K1.11 (+), K2.11 (+), LED2.A, LED4.A, LED5.A, LED6.A, LED7.A, Q2.E, R25.2, R26.2, R35.2, R36.2, R37.2, R42.2, R43.2, R44.2, R50.1, R53.1
-12V: D14.A, IC7.4 (V-), LED3.K (C), R23.1, R30.1
GND: C4.-, C5.-, C6.-, C19.2, C20.-, C29.2, C30.2, C31.2, C32.2, C33.2, C34.2, D14.C, D15.A, D16.A, IC6.6 (S), IC6.7 (VSS), IC6.8 (S), IC7.3 (+IN), IC8.8 (VSS), IC9.12 (GND), IC10.6 (S), IC10.7 (VSS), IC10.8 (S), IC11.7 (S), IC11.8 (VSS), IC11.9 (S), IC12.GND, IC13.7 (S), IC13.8 (VSS), IC13.9 (S), IR1.2 (GND), Q3.E, Q5.E, Q6.E, R21.2, R22.2, R28.1, R31.1, R41.1, R45.1, R46.1, R47.1, R48.1, R49.2, T3.E, T4.E, TR1.9 (4), TR1.13 (5)
unnamed: F1.2, TR1.1, X1.2
unnamed: R57.2, R58.2, R60.2, R61.2, T1.T2 (A2), T2.T2 (A2), TR1.7 (2), X1.1
unnamed: Q3.B, R27.1
unnamed: D10.A, D12.C, TR1.14 (6)
unnamed: D11.A, D13.C, TR1.8 (3)
unnamed: C4.+, C6.+, D10.C, D11.C, IC12.IN
unnamed: C5.+, D12.A, D13.A, R23.2
unnamed: LED3.A, R21.1
unnamed: IR1.1 (OUT), R24.1, R27.2
unnamed: IC6.3 (CLK), IC9.2 (OUT), R37.1
unnamed: LED2.K (C), R22.1
unnamed: Q2.B, R29.2
unnamed: D18.C, Q2.C, R30.2
unnamed: D18.A, R31.2, R32.2
unnamed: C23.1, IC7.2 (-IN), Q4.E, R32.1, R33.1
unnamed: D20.C, D23.C, IC6.10 (R), R46.2
unnamed: C22.1, IC8.4 (A), Q3.C, R26.1, R29.1
unnamed: C23.2, IC7.6 (OUT), IC9.5 (+IN), IC9.7 (+IN), IC9.9 (+IN), IC9.11 (+IN), Q4.C, R33.2
unnamed: Q4.B, R34.1
unnamed: C24.+, IC8.2 (T2), R35.1
unnamed: C24.-, IC8.1 (T1)
unnamed: IC9.4 (-IN), R36.1, R38.2
unnamed: IC9.10 (-IN), R40.1, R41.2
unnamed: IC9.8 (-IN), R39.1, R40.2
unnamed: IC9.6 (-IN), R38.1, R39.2
unnamed: IC6.11 (CLK), IC9.1 (OUT), R42.1
unnamed: IC9.14 (OUT), IC10.3 (CLK), R43.1
unnamed: IC9.13 (OUT), IC10.11 (CLK), R44.1
unnamed: D23.A, IC6.1 (Q), IC11.5 (K), IC11.6 (J)
unnamed: D24.A, IC6.13 (Q), IC11.10 (J), IC11.11 (K)
unnamed: Q5.B, R52.2
unnamed: IC10.13 (Q), IC13.10 (J), IC13.11 (K)
unnamed: C21.-, IC11.4 (R), IC11.12 (R), IC13.4 (R), IC13.12 (R), R49.1
unnamed: D25.A, IC10.1 (Q), IC13.5 (K), IC13.6 (J)
unnamed: IC11.1 (Q), R52.1
unnamed: LED4.K (C), R51.1
unnamed: OK1.2 (C), Q5.C, R51.2
unnamed: Q6.B, R55.2
unnamed: IC11.15 (Q), R55.1
unnamed: LED5.K (C), R54.1
unnamed: OK2.2 (C), Q6.C, R54.2
unnamed: OK1.1 (A), R50.2
unnamed: OK2.1 (A), R53.2
unnamed: F1.1, X2.2, X3.2
unnamed: C27.1, R59.2, R60.1
unnamed: C25.1, R56.2, R57.1
unnamed: C25.2, C26.2, T1.T1 (A1), X2.1
unnamed: C26.1, R58.1
unnamed: C27.2, C28.2, T2.T1 (A1), X3.1
unnamed: OK1.4 (A1), T1.G
unnamed: D26.A, K2.12 (-), R63.2, T3.C
unnamed: C28.1, R61.1
unnamed: OK2.4 (A1), T2.G
unnamed: OK1.6 (A2), R56.1
unnamed: OK2.6 (A2), R59.1
unnamed: R62.1, T3.B
unnamed: K2.1 (O), X5.2
unnamed: K2.7, X5.1
unnamed: LED6.K (C), R63.1
unnamed: D27.A, K1.12 (-), R65.2, T4.C
unnamed: R64.1, T4.B
unnamed: K1.7, X4.1
unnamed: K1.1 (O), X4.2
unnamed: LED7.K (C), R65.1
unnamed: IC13.1 (Q), R64.2
unnamed: IC13.15 (Q), R62.2
unnamed: IC8.7 (!Q), IC11.3 (CLK), IC11.13 (CLK), IC13.3 (CLK), IC13.13 (CLK)
unnamed: D22.C, D25.C, IC10.10 (R), R48.2
unnamed: D19.C, IC6.4 (R), R45.2
unnamed: C22.2, D16.C, D19.A, D20.A, D21.A, D22.A, R28.2, R34.2
unnamed: D21.C, D24.C, IC10.4 (R), R47.2

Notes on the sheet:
220V | 50Hz
MINI-PROJET ELECTRONIQUE 1AGE\2016-2017 Télécomende Infrarouge a quatre canaux
M.BOUSSAMA

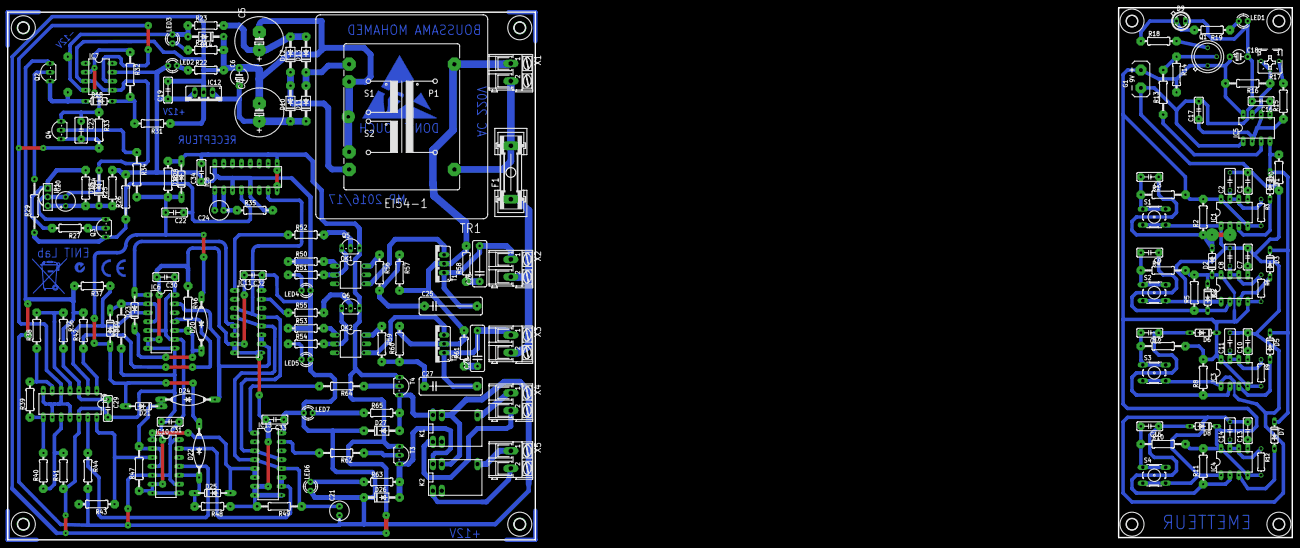
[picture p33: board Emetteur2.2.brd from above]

Board: 2 copper layers, 366.4 x 151.8 mm, 184 parts (1 on the bottom side), 107 nets.

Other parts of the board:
U$1: DON'T TOUCH; ESD
U$3: MUELLTONNE_10.00
U$11: CE_5MM
U$12: C_TICK-3MM

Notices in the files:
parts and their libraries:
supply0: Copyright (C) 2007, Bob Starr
